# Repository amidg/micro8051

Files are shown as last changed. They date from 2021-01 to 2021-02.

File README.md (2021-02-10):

# micro8051
micro8051 is the open-source implementation of the outdated Intel's architecture MCS-51 commonly known by the microcontroller 8051. 
Github contains only my last polished revision (Rev.A5). If you would like to request older versions (explained below), please, contact at dgusev@sfu.ca

Some background:
Initially I started this project around 2 years ago while taking MSE352 "Digital Logic and Microcontrollers" at Simon Fraser University, Canada. 
This project was supervised by Dr. Mohammad Narimani and Dr. Amr Marzouk. 

Main goal of the project was to reduce the cost of equipment and provide students with advanced and open-source alternative for the board designed by MikroElektronika which is costly and lacks modern functionality such as common USB Type-C port or 8051-to-USB. Additionally, board my MikroElektronika is quite huge and not breadboard friendly. 

Achieved results:
- Total cost of purchasing was reduced by half (from $90 to ~$40, even with fabrication and parts located in NA)
- Smaller breadboard-friendly form-factor
- In-built Arduino Uno R3
- 8051 can communicate to the USB directly (UART<->USB)

Revision History:
- Rev.A1: FTDI232 (SMD) + Arduino Uno (DIP) + 8051 (DIP)
- Rev.A2 (breadboard only): MCP2221A (DIP) + Arduino Uno (DIP) + 8051 (DIP)
- Rev.A3: Rev.A2 + 2x MCP2221A for 8051 direct USB communication
- Rev.A4: ATmega16u2 (Hoodloader @ SMD) + ATmega2560 (extra @ SMD) + 8051 (SMD)
- Rev.A5 (current): FT231XS + ATmega328P (SMD, UART<->SPI flashing) + 8051 (SMD) + UART bridge

Important notes: 
When 8051 communicates to USB port, Arduino cannot take over the USB port. However, USB functionality can be controlled both manually and via 8051. See schematic for details.

Gerbers and BOMs are located in Manufacturing folder. 

Enjoy!

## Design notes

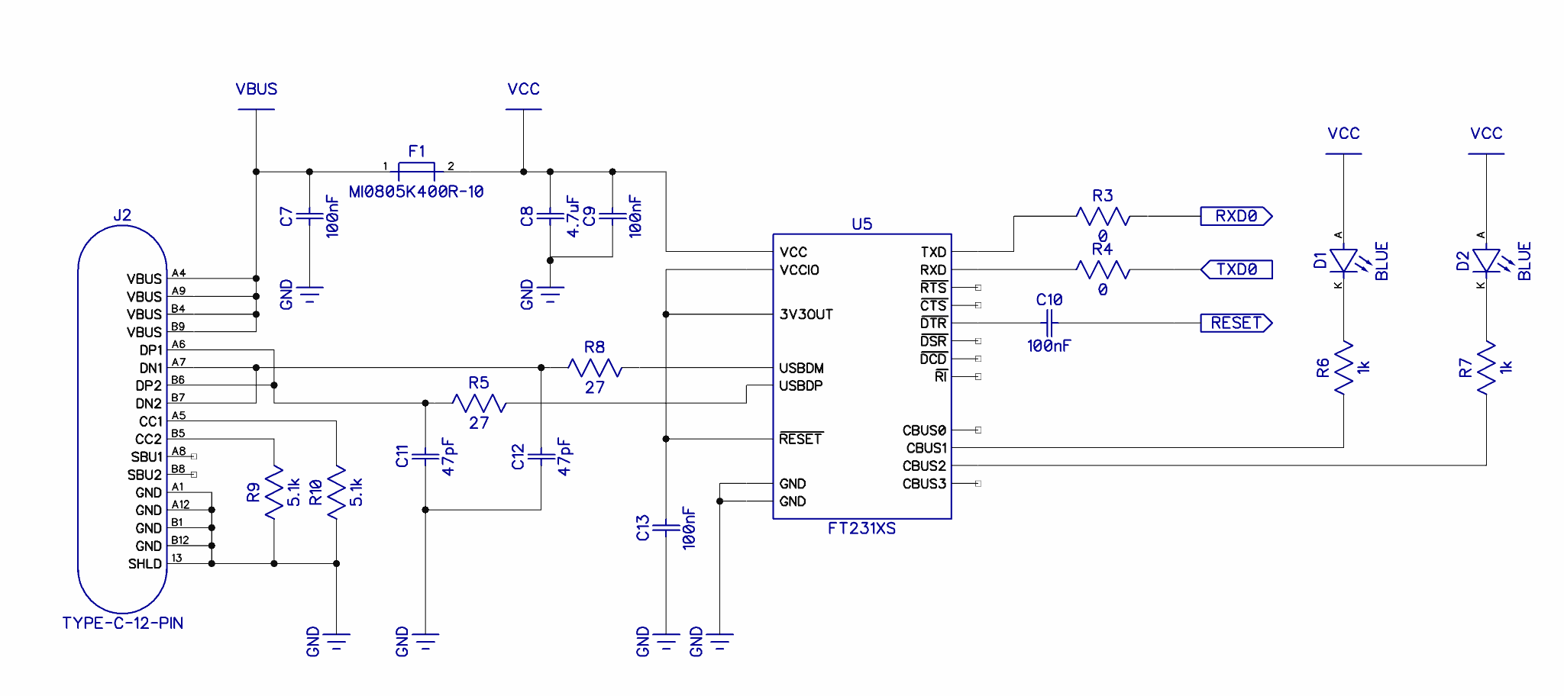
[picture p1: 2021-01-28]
Reference/typical-usb-c-implementation.png

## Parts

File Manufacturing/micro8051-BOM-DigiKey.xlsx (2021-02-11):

Manufacturer Part Number | Digi-Key Part Number | Customer Reference | Reference Designator | Quantity | Unit Price
150080GS75000 | 732-4983-1-ND | SMD mono-color Chip LED, WL-SMCW, Green | 3V3, 5V | 2 | 0.25
AT89S52-24AUR | AT89S52-24AURCT-ND |  | 8051 | 1 | 2.9
B3U-1000P | SW1020CT-ND | SWITCH TACTILE SPST-NO 0.05A 12V | 8051-RST, ISP-RST | 2 | 1.36
150080SS75000 | 732-4985-1-ND | SMD mono-color Chip LED, WL-SMCW, Super Red | 8051-UART | 1 | 0.25
C0805C470K5RACAUTO | 399-C0805C470K5RACAUTOCT-ND |  | C1, C2 | 2 | 0.35
CL21B104KBFXPJE | 1276-CL21B104KBFXPJECT-ND | CAP CER 0.1UF 50V X7R 0805 | C3, C5, C8, C9, C11, C15 | 6 | 0.33
CL21A475KBQNNNE | 1276-1248-1-ND | CAP CER 4.7UF 50V X5R 0805 | C4, C10, C14 | 3 | 0.4
CL31B106MOHNNNE | 1276-6641-1-ND | Capacitor, Tantalum, 10 uF, +/- 10%, 16 V, -55 t | C6, C7 | 2 | 0.3
CC0805JRNPOABN220 | 311-4248-1-ND |  | C12, C13 | 2 | 0.26
C0805C330J1GACTU | 399-8061-1-ND | CAP CER 33PF 100V 5% NP0 0805 | C16, C17 | 2 | 0.17
TMK212B7105KGHT | 587-3477-1-ND |  | C18 | 1 | 0.28
150080BS75000 | 732-4982-1-ND | SMD mono-color Chip LED, WL-SMCW, Blue | D8 | 1 | 0.25
61301021121 | 732-2672-ND | THT Vertical Pin Header WR-PHD, Pitch 2.54 mm, D | debug | 1 | 1.44
MICROSMD050F-2 | MICROSMD050F-2CT-ND | PTC RESET FUSE 13.2V 500MA 1210 | F1 | 1 | 0.57
61302011121 | 732-5329-ND | THT Vertical Pin Header WR-PHD, Pitch 2.54 mm, S | J1, J2 | 2 | 1.59
2N7002PW,115 | 1727-4793-1-ND | MOSFET N-CH 60V 0.31A SOT323 | Q1 | 1 | 0.3
RT0805FRE0722RL | 13-RT0805FRE0722RLCT-ND |  | R1, R2 | 2 | 0.15
RT0805FRE075K11L | 13-RT0805FRE075K11LCT-ND | 5K11 0.125W 1% 0805 (2012 Metric) SMD | R3, R4 | 2 | 0.15
RT0805FRE071KL | YAG1240CT-ND |  | R5, R6, R7, R9, R10, R14, R26 | 7 | 0.15
RT0805FRD07100KL | 13-RT0805FRD07100KLCT-ND | Chip Resistor, 100 KOhm, +/- 1%, 0.125 W, -55 to | R8 | 1 | 0.19
RT0805FRE0710KL | YAG1239CT-ND | Chip Resistor, 10 KOhm, +/- 1%, 0.125 W, -55 to | R11, R12, R13, R15, R16, R17, R18, R19, R20, R21, R22, R24, R25 | 13 | 0.118
AC0805FR-7W100RL | 13-AC0805FR-7W100RLCT-ND | Chip Resistor, 100 Ohm, +/-1%, 0.125 W, -55 to 1 | R23 | 1 | 0.15
150080YS75000 | 732-4987-1-ND | SMD mono-color Chip LED, WL-SMCW, Yellow | RX, TX | 2 | 0.25
FT231XS-R | 768-1129-1-ND | IC USB SERIAL FULL UART 20SSOP | U1 | 1 | 3.12
SN74LV4052APWR | 296-3831-1-ND | Dual 4-Channel Analog Multiplexer/Demultiplexer, | U3 | 1 | 0.72
SN74LVC2G08DCUR | 296-13264-1-ND | Dual 2-Input Positive-AND Gate, DCU0008A, LARGE | U4 | 1 | 0.59
ATMEGA328P-AN | ATMEGA328P-AN-ND | 8-bit AVR Microcontroller, 32KB Flash, 1KB EEPRO | U5 | 1 | 3.59
A6S-1104-H | Z5187-ND | SWITCH SLIDE DIP SPST 25MA 24V | UART-EN | 1 | 2.23
USB4085-GF-A | 2073-USB4085-GF-ACT-ND | CONN RCPT USB2.0 TYPEC 16POS | USB-C | 1 | 1.85
FC4STCBMF11.0592-BAG200 | 631-1103-ND | Crystal, 11.0592 MHz, 18 pF, -20 to 70 degC, 2-P | Y2 | 1 | 0.52
FC4STCBMF16.0-BAG200 | 631-1108-ND | Crystal, 16 MHz, 18 pF, -20 to 70 degC, 2-Pin TH | Y1 | 1 | 0.52
XC6210B332MR-G | 893-1075-1-ND |  | U2 | 1 | 1.25

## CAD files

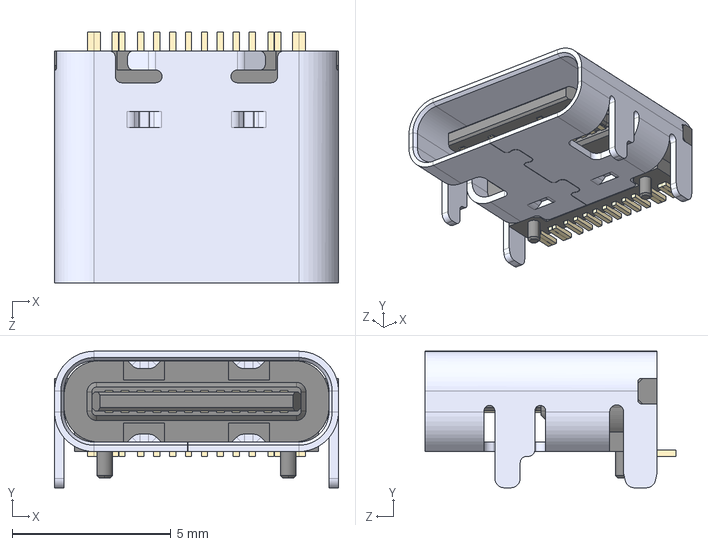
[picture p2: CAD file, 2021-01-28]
Electrical/Import/TYPE-C-31-M-12/TYPE-C-31-M-12--3DModel-STEP-56544.STEP
8.94 x 4.30 x 7.90 mm

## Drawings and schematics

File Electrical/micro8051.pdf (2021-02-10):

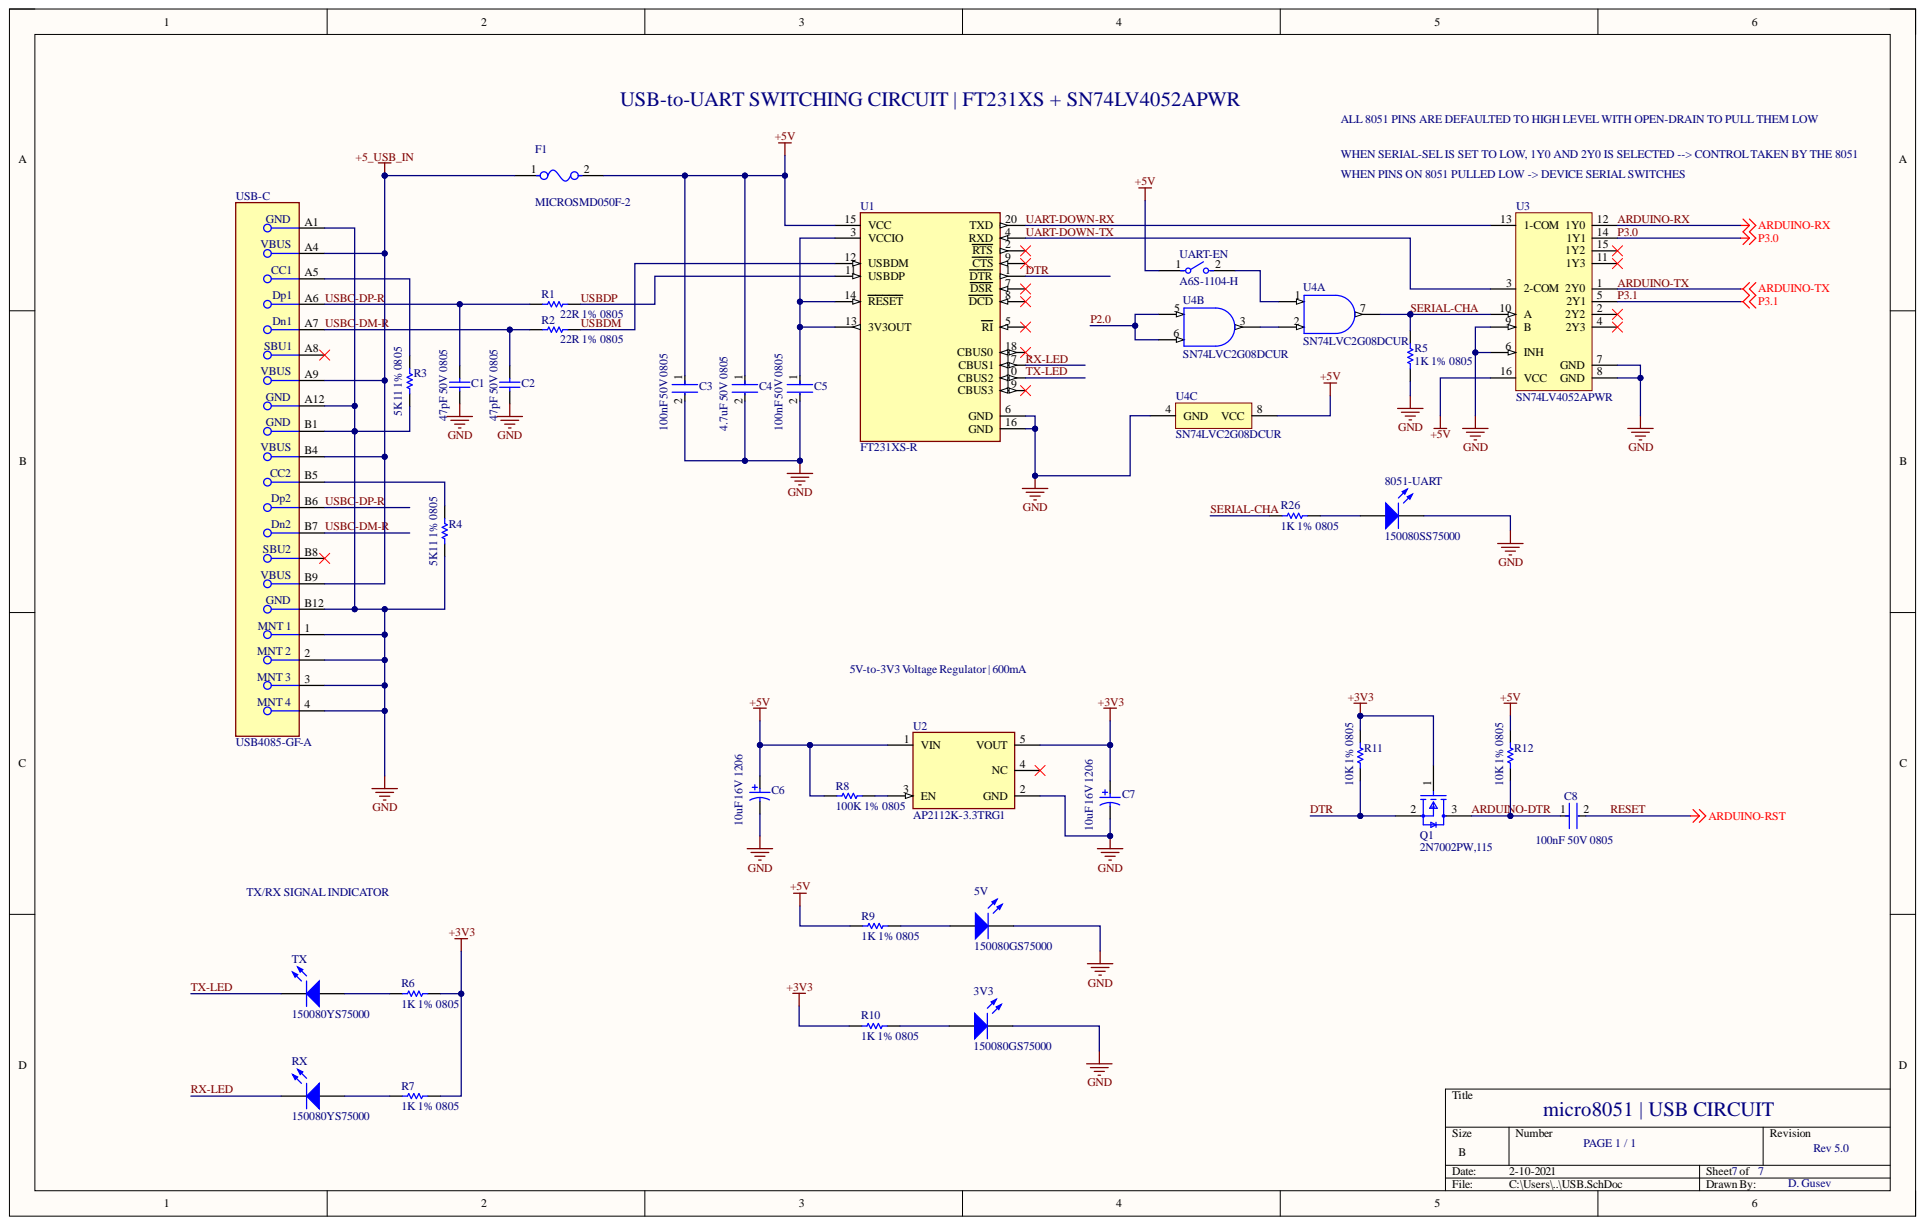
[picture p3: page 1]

USB-to-UART SWITCHING CIRCUIT | FT231XS + SN74LV4052APWR

ALL 8051 PINS ARE DEFAULTED TO HIGH LEVEL WITH OPEN-DRAIN TO PULL THEM LOW

WHEN SERIAL-SEL IS SET TO LOW, 1Y0 AND 2Y0 IS SELECTED --> CONTROL TAKEN BY THE 8051
WHEN PINS ON 8051 PULLED LOW -> DEVICE SERIAL SWITCHES

VCCIO 3 | UART-DOWN-TX | | 2-COM 3

USBDM 12 | DTR

C3 | C4 | | RESET 14

1 | 7 SERIAL-CHA | A 10

TX/RX SIGNAL INDICATOR

Size B | Number PAGE 1 / 1 | Revision Rev 5.0

Date: 2-10-2021 | Sheet of 7 7
File: C:\Users\..\USB.SchDoc | Drawn By: D. Gusev

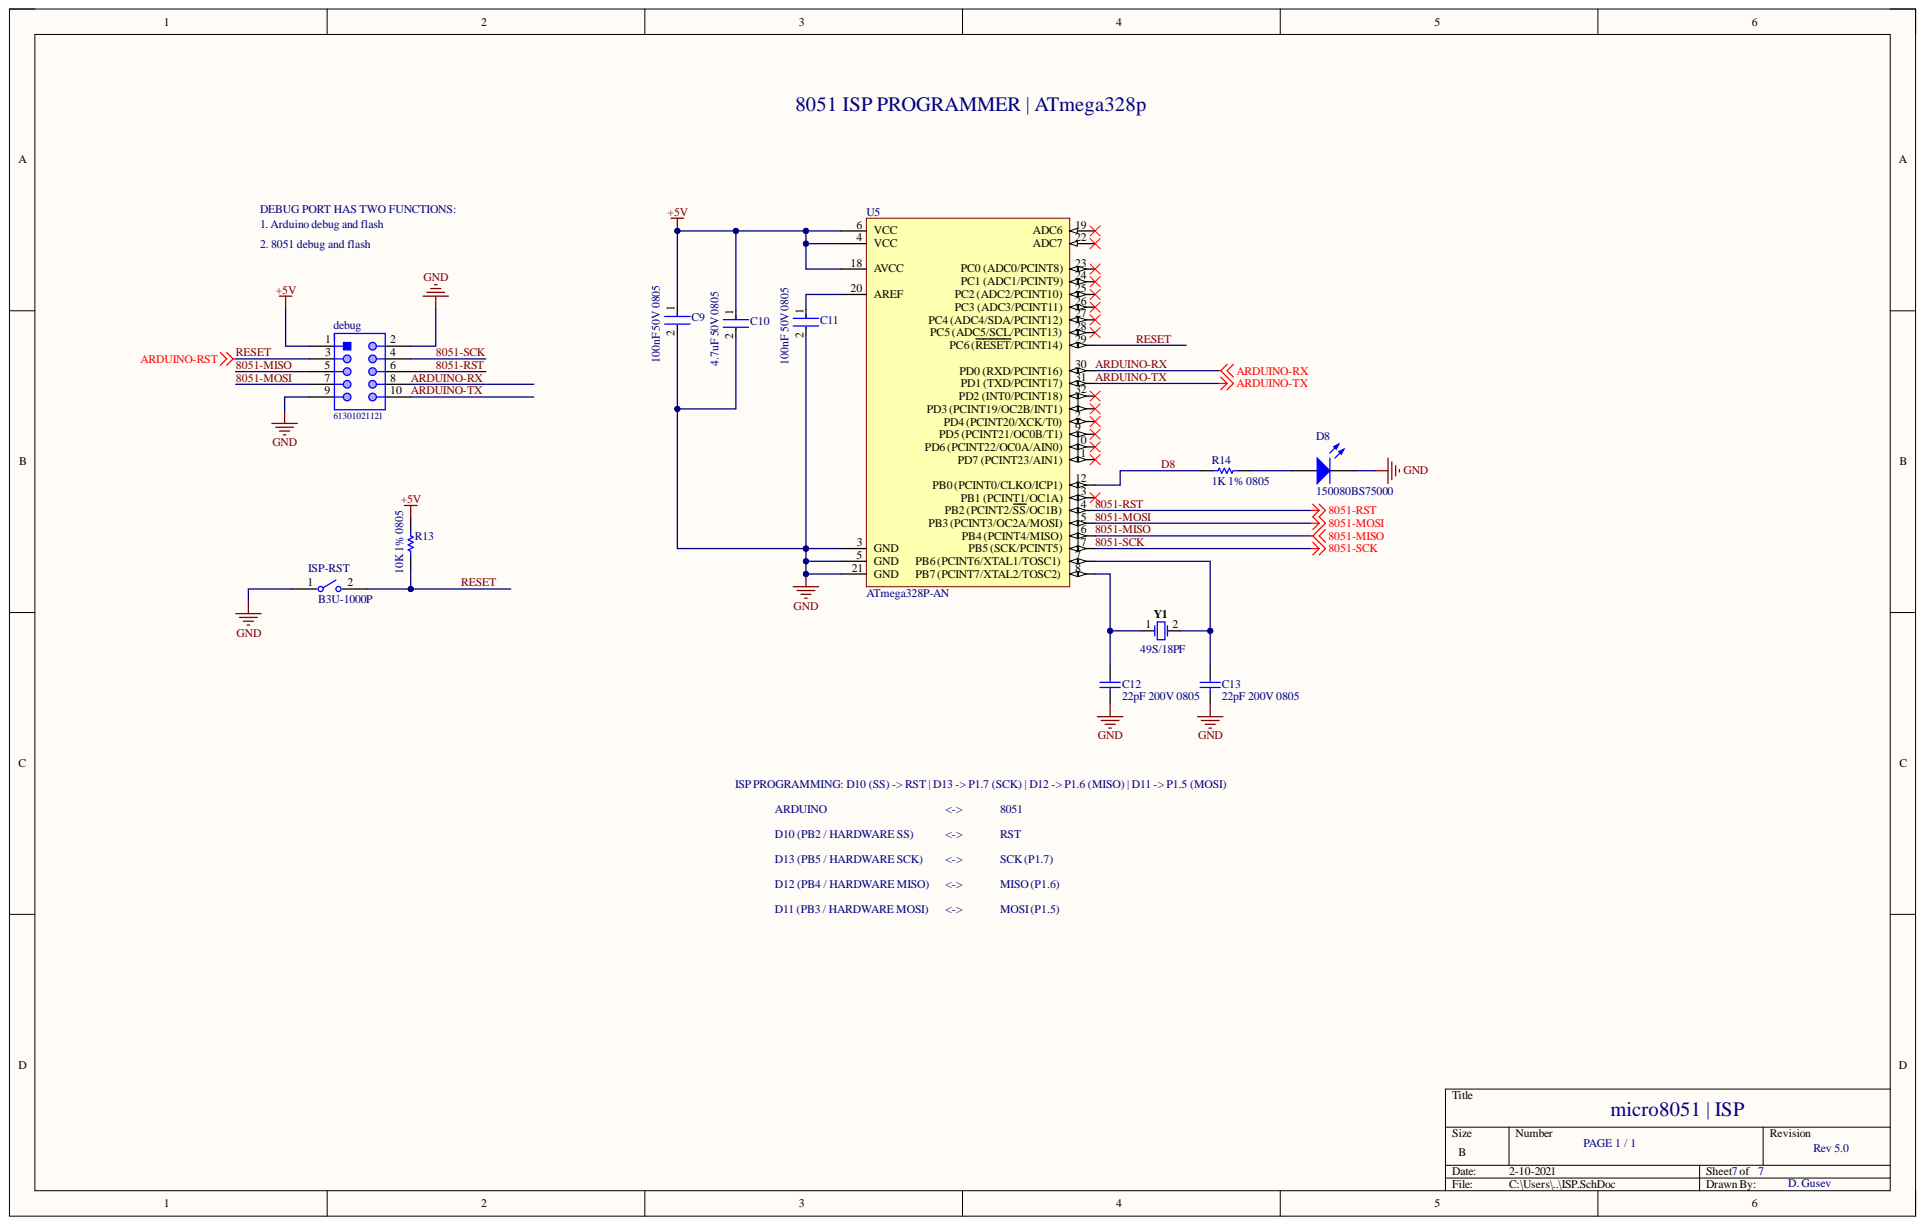
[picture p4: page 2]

DEBUG PORT HAS TWO FUNCTIONS:
1. Arduino debug and flash
2. 8051 debug and flash

ISP PROGRAMMING: D10 (SS) -> RST | D13 -> P1.7 (SCK) | D12 -> P1.6 (MISO) | D11 -> P1.5 (MOSI)

Size B | Number PAGE 1 / 1 | Revision Rev 5.0

Date: 2-10-2021 | Sheet of 7 7
File: C:\Users\..\ISP.SchDoc | Drawn By: D. Gusev

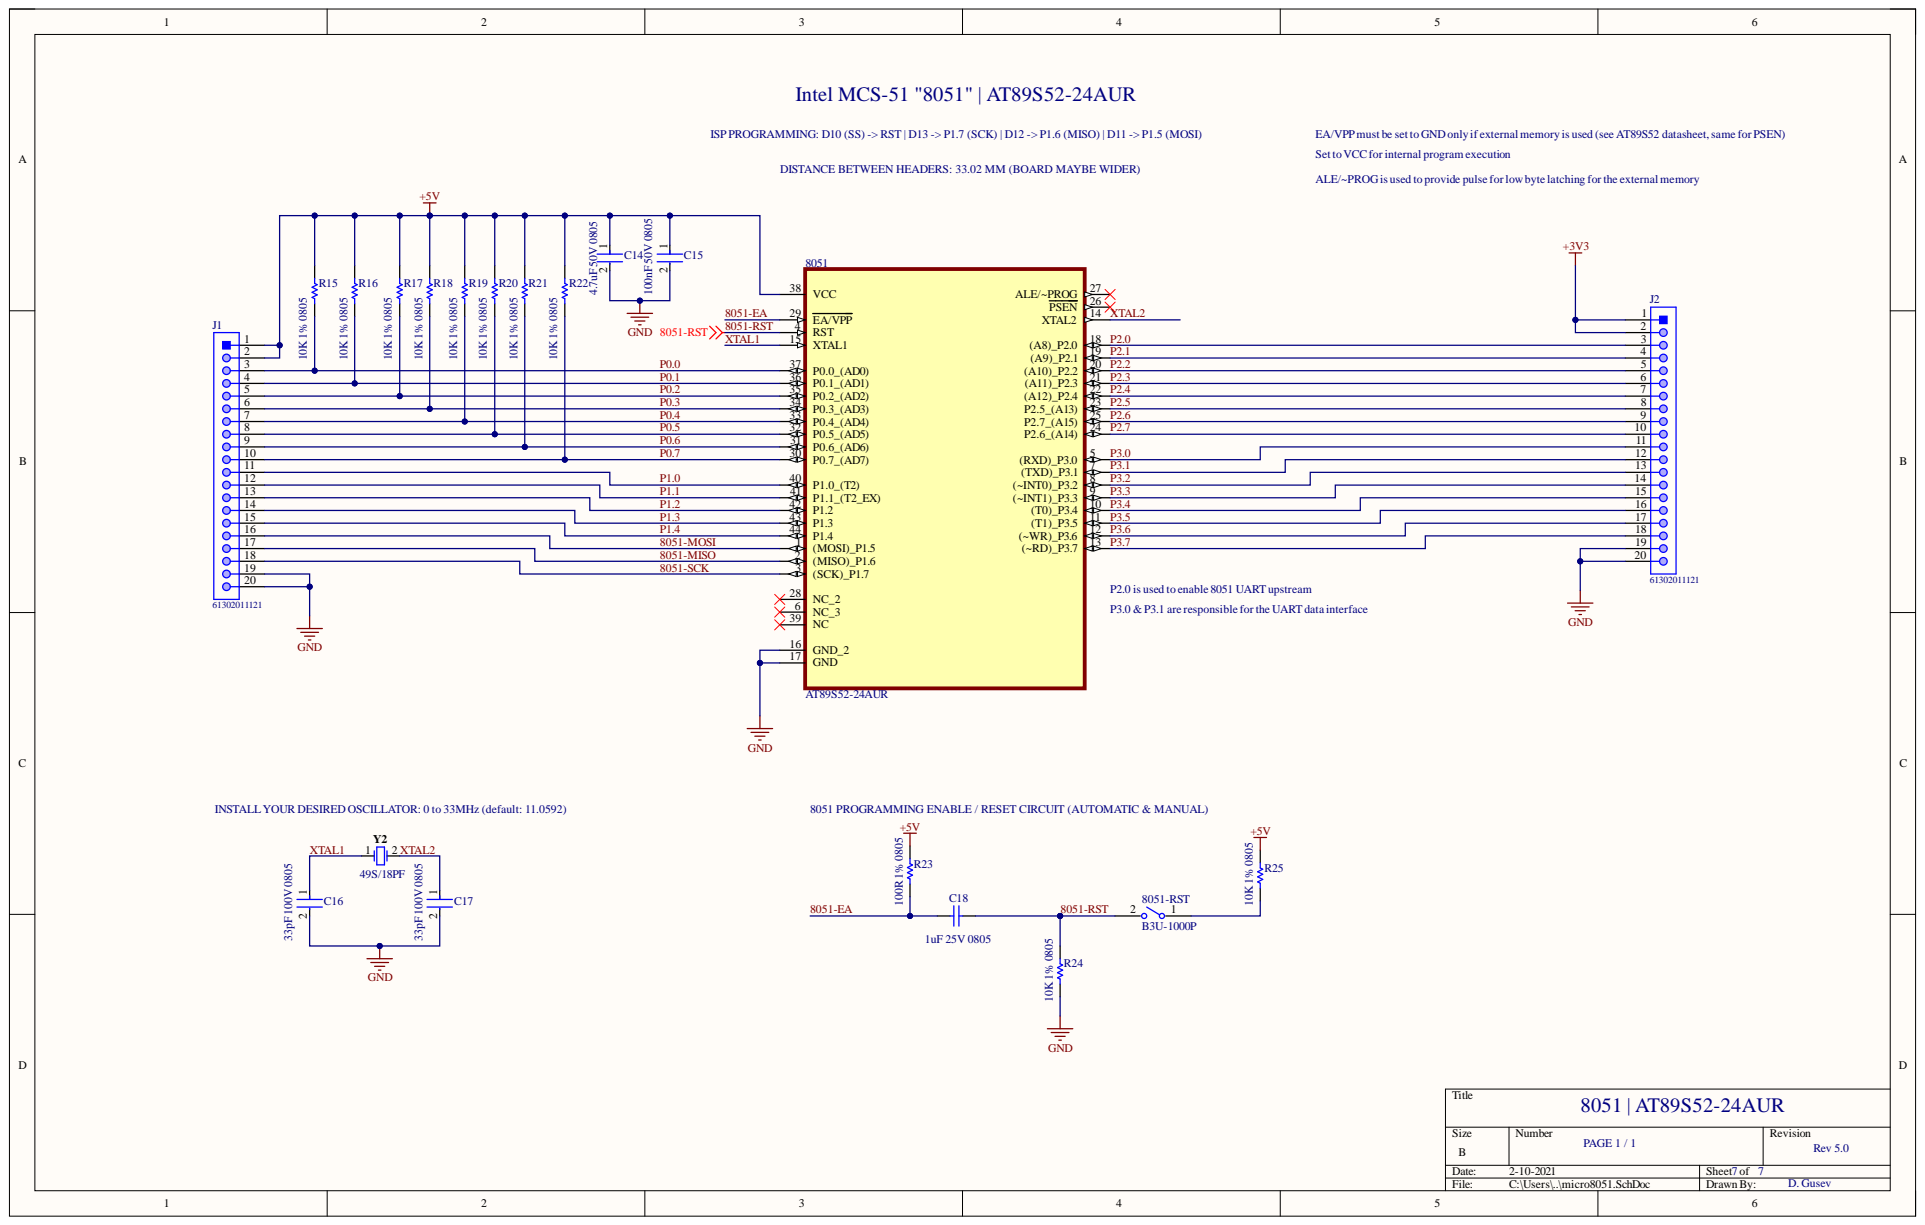
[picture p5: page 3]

17 | 8051-M O S I | 1 | | P3. 7 | 19
18 | 8051-M I S O | 2 | A L ) | | 20
19 | 8051-SC K | 3
20 | | R E D OSC IL L AT O R : 0

Si z e | Num b er PA G E 1 / 1 | Revi s i on Rev 5.0

e : 2-10-20 2 1 | Sheet of 7 7
Fi l e : C : \U ser s \..\ m icro8051.S chDo c | D rawn By: D. Gusev

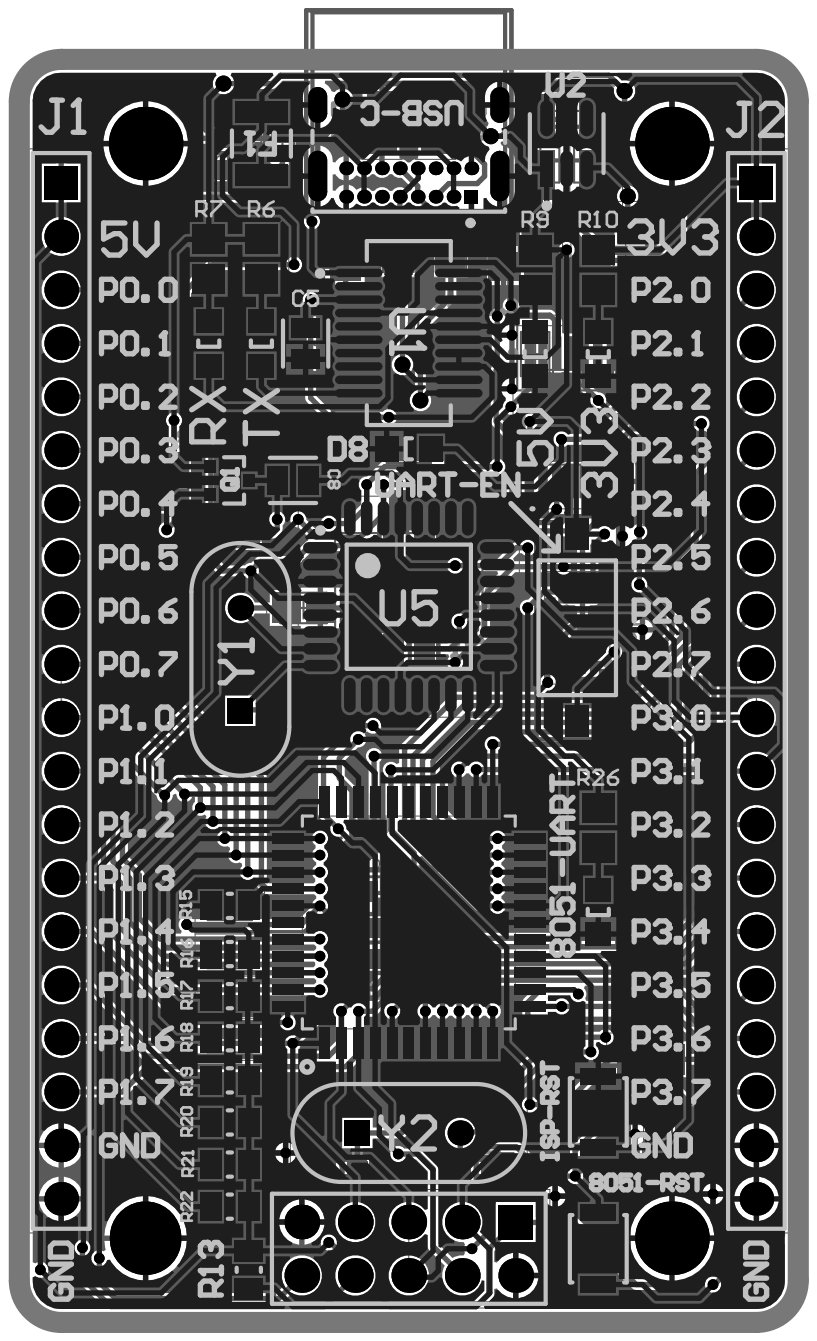
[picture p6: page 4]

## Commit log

2021-01-28 Updated serial model
    [8051.SchDoc, ArduinoISP.SchDoc, HRO_TYPE-C-31-M-12.PcbLib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]
2021-01-29 board is ready for routing
    [8051.SchDoc, ISP.SchDoc, USB.SchDoc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]
2021-01-30 50% done routing
    [ISP.SchDoc, USB.SchDoc, micro8051.PcbDoc]
2021-01-30 main components are placed
    [USB.SchDoc, micro8051.PcbDoc]
2021-01-31 routed 100%
    [ISP.SchDoc, micro8051.PcbDoc]
2021-01-31 production ready
    [micro8051.GBL, micro8051.GBO, micro8051.GBP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]
2021-02-01 manufacturing data updated
    [micro8051.GBL, micro8051.GBO, micro8051.GBP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]
2021-02-10 manufacturing BOM added from Digi-Key
    [micro8051-BOM-DigiKey.xlsx]
2021-02-10 PDF schematic added
    [ISP.SchDoc, USB.SchDoc, micro8051.PrjPcb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]
2021-02-11 bom updated, just upload to digikey
    [micro8051-BOM-DigiKey.xlsx, micro8051.PrjPcb]
